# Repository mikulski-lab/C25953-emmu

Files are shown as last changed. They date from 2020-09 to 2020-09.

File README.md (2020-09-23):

# Atari XE C25953 emmu unit replicated in GAL16v8 and GAL20v10

As the happy owner of an Atari 65XE I wanted to upgrade it and have fun with full 130kB of RAM. After browsing the internet I learned that C25953 is very hard to find. There are some GAL implementations, however those require an extra D latch. Unfortunately my motherboard doesn't support such a solution.

After quick investigation, looking into C25953 discrete IC implementation's schematic, it turned out that it was possible to fully replicate C25953 logic with cheap, old, yet still available GALs (GAL16v8 and GAL20v10). The only trick was to generate the missing latched HALT signal used in logic equations.
Unfortunately due to the GALs' hardware restrictions __1:1 pin compatible__ replica __was not feasible__ forcing external wirings.

## Structure of the repository
  - gal16v8 - best to use with a custom PCB:
    - winculp - implementation in CUPL, jedec files, etc. 
    - graphics - photos of the implementation
    - kicad - kicad schematics/pcb and gerber files

  - gal22v10 - can be directly mounted in the socket, however requires some basic wiring and soldering on top of the IC:
    - winculp - implementation in CUPL, jedec files, etc.
    - graphics - photos of the implementation and wiring diagrams  

## Test result with "Video Blitz" demo

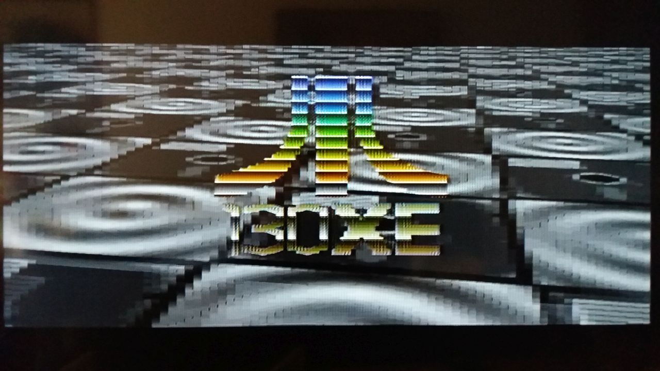
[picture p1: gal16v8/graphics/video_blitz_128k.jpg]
Video Blitz


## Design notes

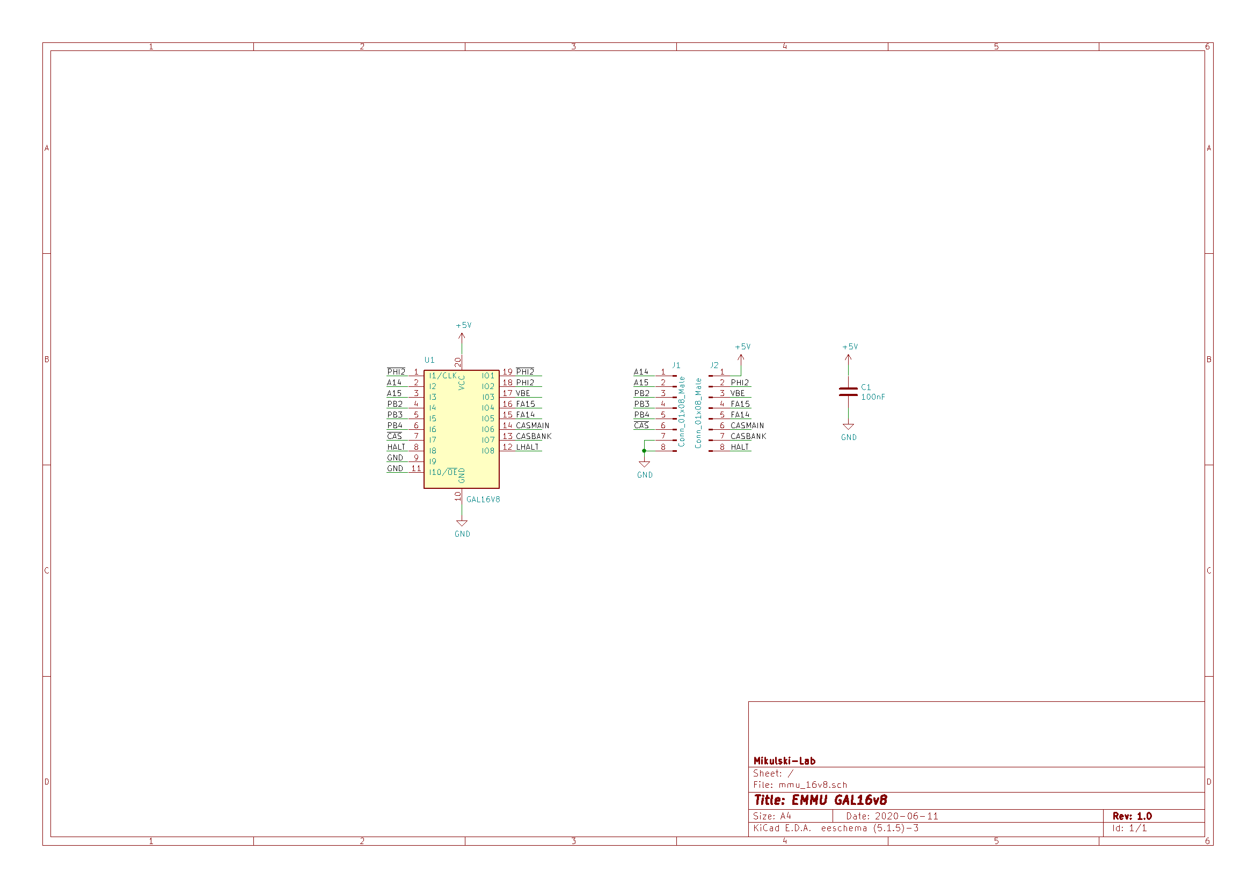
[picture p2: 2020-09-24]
gal16v8/graphics/mmu_16v8_schematic.png

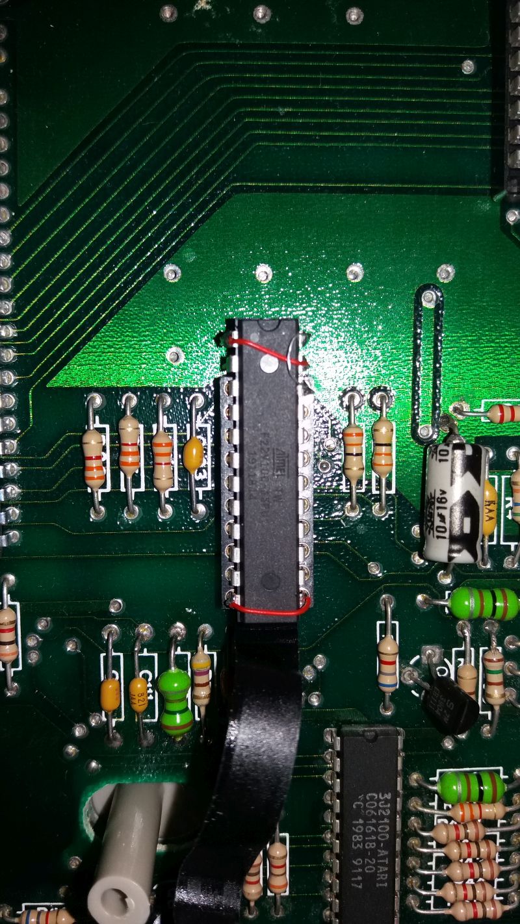
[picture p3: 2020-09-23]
gal22v10/graphics/mmu_22v10_real_no_tape.jpg

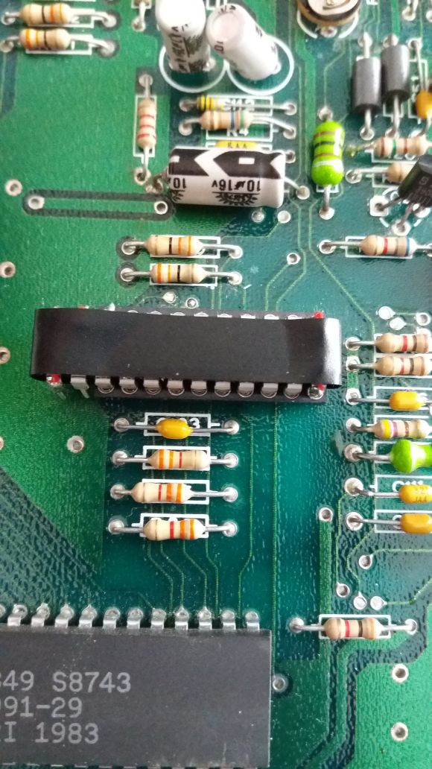
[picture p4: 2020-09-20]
gal22v10/graphics/mmu_22v10_real.jpg

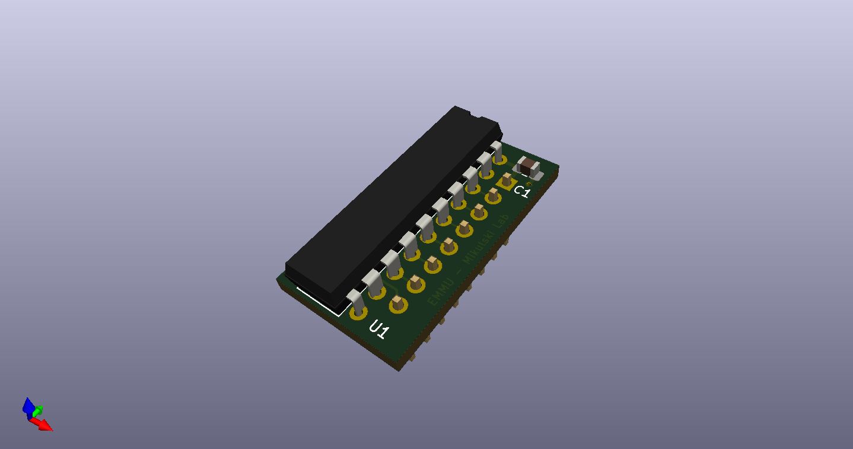
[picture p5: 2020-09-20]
gal16v8/graphics/mmu_16v8_kicad.jpg

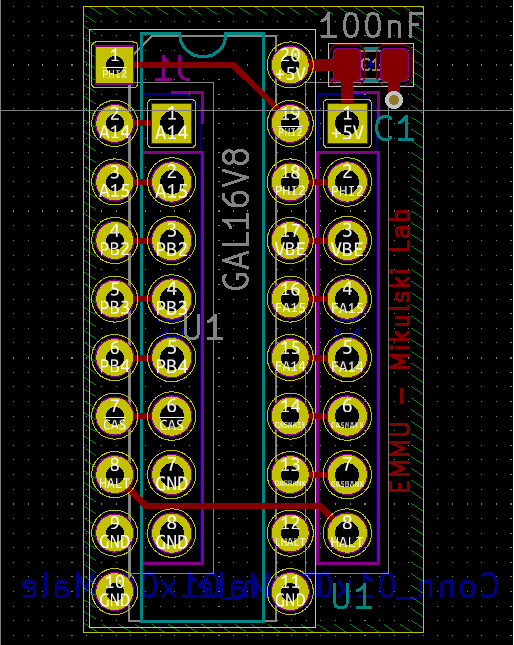
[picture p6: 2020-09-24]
gal16v8/graphics/mmu_16v8_pcb.png

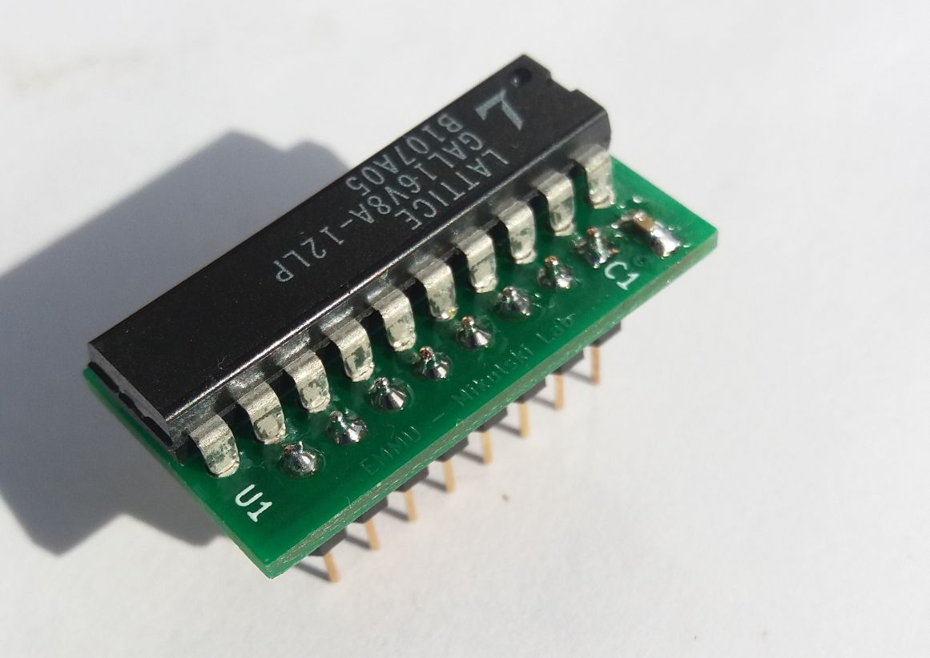
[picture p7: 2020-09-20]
gal16v8/graphics/mmu_16v8_real.jpg

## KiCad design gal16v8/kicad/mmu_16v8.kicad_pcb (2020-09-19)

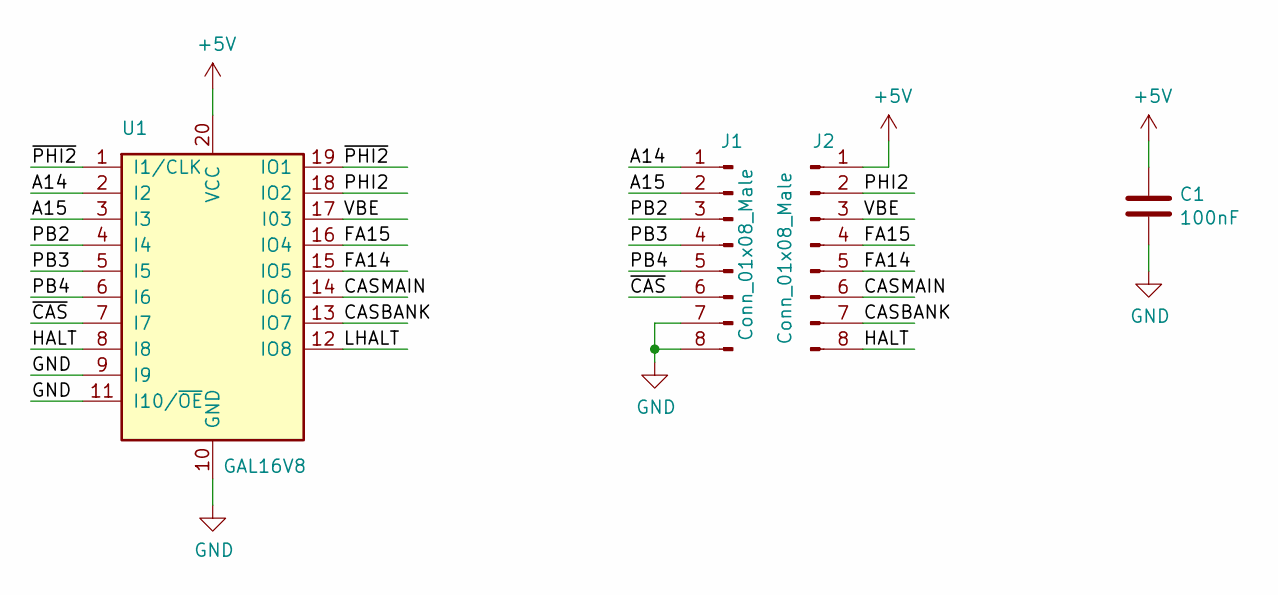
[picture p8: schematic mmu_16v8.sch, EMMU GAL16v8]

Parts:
C1: 100nF; C_0805_2012Metric_Pad1.15x1.40mm_HandSolder
J1, J2: Conn_01x08_Male; PinHeader_1x08_P2.54mm_Vertical
U1: GAL16V8; DIP-20_W7.62mm

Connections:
+5V: C1.1, J2.1, U1.20 (VCC)
/A14: J1.1, U1.2 (I2)
/A15: J1.2, U1.3 (I3)
/CASBANK: J2.7, U1.13 (IO7)
/CASMAIN: J2.6, U1.14 (IO6)
/FA14: J2.5, U1.15 (IO5)
/FA15: J2.4, U1.16 (IO4)
/HALT: J2.8, U1.8 (I8)
/LHALT: U1.12 (IO8)
/PB2: J1.3, U1.4 (I4)
/PB3: J1.4, U1.5 (I5)
/PB4: J1.5, U1.6 (I6)
/PHI2: J2.2, U1.18 (IO2)
/VBE: J2.3, U1.17 (I03)
/~CAS: J1.6, U1.7 (I7)
/~PHI2: U1.1 (I1/CLK), U1.19 (IO1)
GND: C1.2, J1.7, J1.8, U1.9 (I9), U1.10 (GND), U1.11 (I10/~OE~)

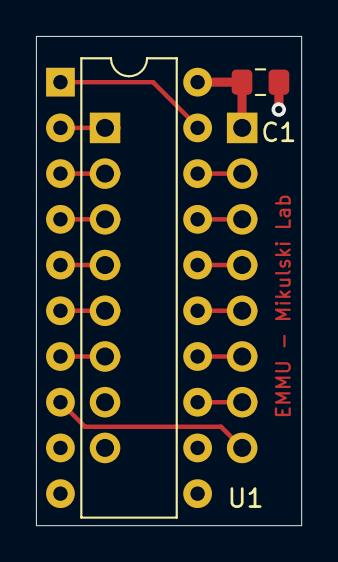
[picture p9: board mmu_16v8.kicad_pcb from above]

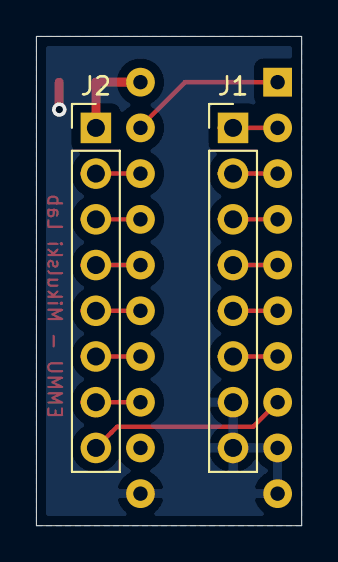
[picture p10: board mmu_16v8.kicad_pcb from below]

Board: 2 copper layers, 14.7 x 27.2 mm, 4 parts (2 on the bottom side), 16 nets.

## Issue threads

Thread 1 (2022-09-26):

Followed instructions for the GAL22v10B version but have issues...

mjcargill, 2022-09-26:
Hi,

I followed the instructions:

1. Socketed the extra RAM right hand bank sockets and put 8 x 4164 chips in them
2. Programmed the 22V10B GAL with the appropriate JED file from your github folder for the 22V10B, connected the pins on the chips as in your image with wire
3. Placed in the EMMU socket (U34) with the 1st 2 pins on each side of the 22V10B hanging off of the front of the socket.

The 65XE starts fine, but when I load some 130XE games, I get a message either telling me that I need the extra 64K to start the game, or the game requires a 130XE machine.

Do I need to use the 74LS95 at U35 too?  I didn't think if using the 22V10 that I needed it.

I would appreciate any help you can give?

Many thanks,

Mark.

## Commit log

2020-09-19 Switch to GPL prior initial commit of the source code
2020-09-19 Initial commit of the source files, etc.
    [mmu_16v8-B_Cu.gbr, mmu_16v8-B_Mask.gbr, mmu_16v8-B_SilkS.gbr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]
2020-09-24 Schematic and pcb exported to PNG
